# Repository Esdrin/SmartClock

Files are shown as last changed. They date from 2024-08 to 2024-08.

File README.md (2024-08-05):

# SmartClock

如你所见，这是一个基于`esp32的智能时钟`项目

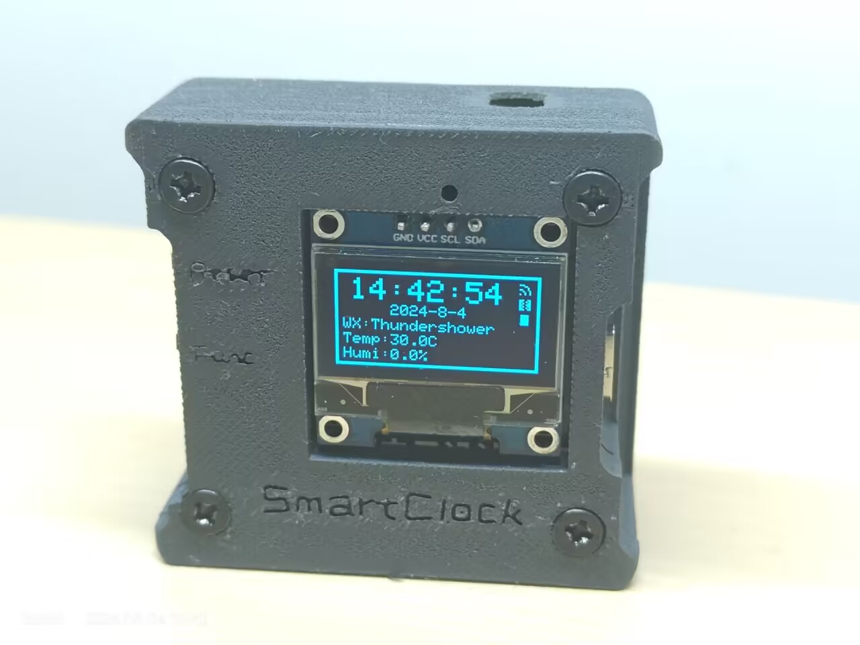
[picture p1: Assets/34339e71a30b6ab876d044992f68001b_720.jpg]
34339e71a30b6ab876d044992f68001b_720


## 前言

本项目自开始（`嘉立创第九届电子设计大赛`）至结束总共花了差不多`1个月`时间，我是一个电设小白，我在这一个月中学习了一些奇奇怪怪有用的知识，这边感谢一下群里的各位佬对我的大力支持，我能`独立完成`这个项目真的很开心（快猝死了）。

本项目为`首次公开`，为`本人原创`项目。项目`未曾在别的比赛中获奖`。

## 项目介绍

本项目是一款针对现代智能家居环境设计的`温湿度监测与时间管理装置`，旨在解决家庭及小型办公空间对环境舒适度与时间同步管理的需求。通过集成`ESP32微控制器`和`SHT40传感器`，我实现了一套`实时监测并远程报告室内温度和湿度`的系统，有效提升了居住和工作环境的舒适度。~~低功耗设计~~和`内置电池`确保了设备的持续运行，无需频繁充电。同时，模块`具备时钟`功能，解决了家中或办公室缺少统一时间显示的问题，方便用户安排日程。

## 复刻金额

如果你是一个专业的电子工程师，那么`复刻的成本在45RMB左右`。

如果不是，那么请准备好以下工具：焊台、电烙铁、热风枪等焊接器具。

## 功能列表

- [x] 温湿度检测（盛思锐的sht40模块）
- [x] 时间显示（网络ntp）
- [x] 日期显示（时间转换）
- [x] 天气显示（心知API）
- [x] 温度过热报警
- [x] MQTT服务的支持（或许你可以连到米家上？）
- [x] 允许使用web服务器进行配置
- [x] UI图像（自己画的，勿喷）

##  文件夹目录

- Firmware：本项目的代码，基于PlatformIO平台
- Model： 本项目的模型文件，基于soildworks 2024
- Picture：本项目的UI图片，自己PS画的
- OrderFile：下单文件
- Assets：Markdown资源文件

## 功能简介

### 主屏幕

如图所见，这是它的`主屏幕`。

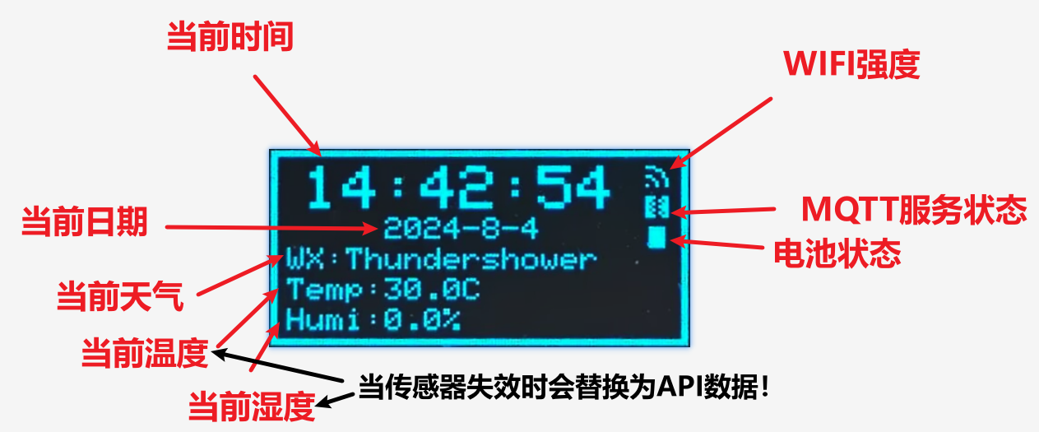
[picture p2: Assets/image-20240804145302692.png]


### 按钮功能

侧边使用双按钮，分别为`Reset（重置按钮）`和`Func（功能）`

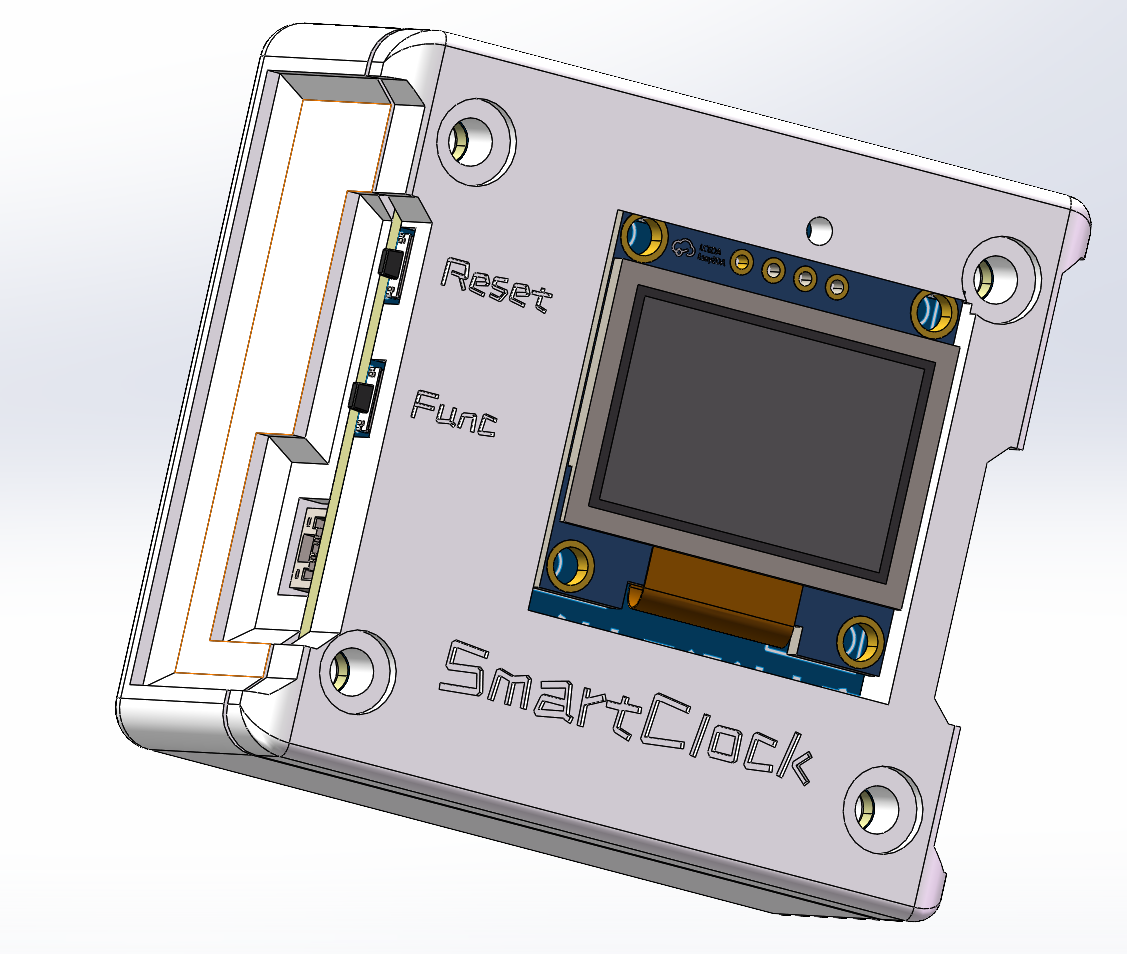
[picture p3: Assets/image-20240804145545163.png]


#### Reset按钮

- **重启**（按1s后松开）：`立马`校准时钟，天气等。
- **重置**（长按5s以上）：`重新设置`WIFI、服务器、天气API等参数。

#### Func按钮

等你创造（写一些时钟不该有的功能的任务就交给你们了！）

### 主控

采用esp32，集成WIFI、蓝牙，淘宝上15块钱包邮到家。

### 配置界面

第一次启动会自动进入配置模式，你也可以使用下面的`reset按键`进行重置参数后也会自动进入。

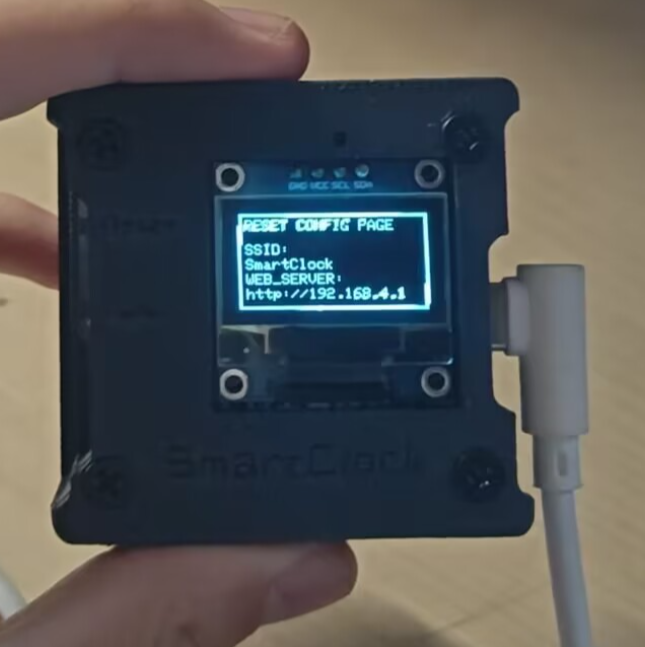
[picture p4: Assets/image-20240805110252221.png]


配置过程：

- 首先你需要找到一个叫做`SmartClock`的WIFI并`连接`。（可以在`Firmware/src/Config.h`中调节`AP_NAME`来更改WIFI名称）
- 浏览器中输入小屏幕中的`WEB_SERVER`地址，也可以下拉通知栏点击`登录到WLAN网络`。
- 按照下图进行配置具体参数。

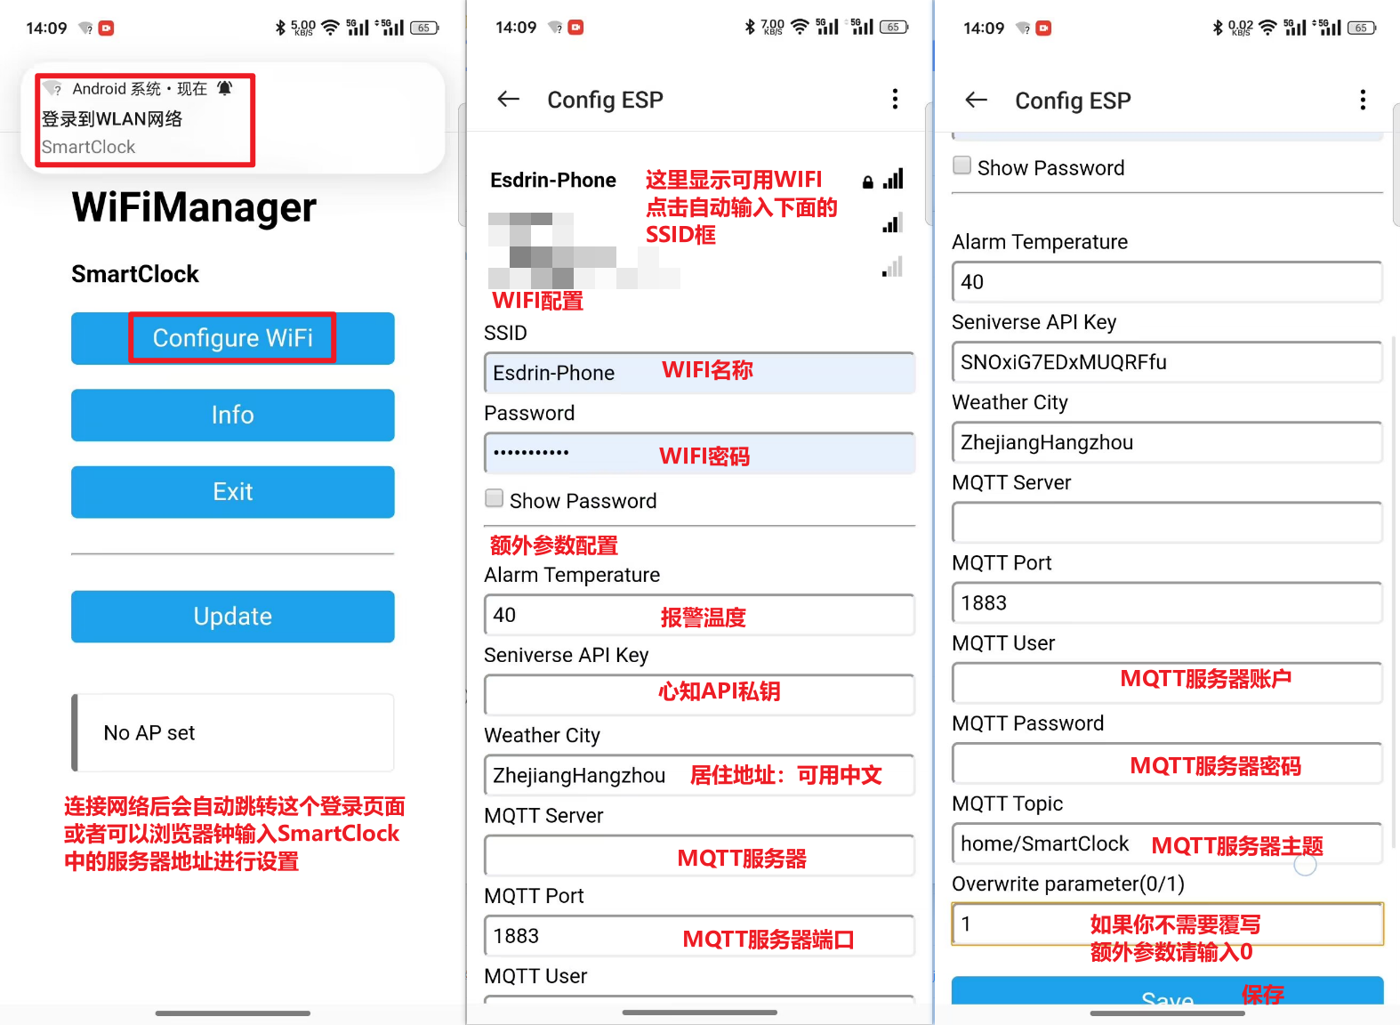
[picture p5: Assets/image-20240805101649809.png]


### 温度采集模块

采用`SHT40`模块，可以使用嘉立创的[SHT40-AD1B with pin模块](https://item.szlcsc.com/item/24072575.html),也可以淘宝上去买这个芯片（4块包邮）

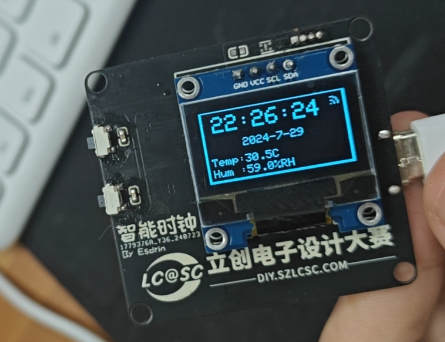
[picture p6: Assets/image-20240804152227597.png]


### OLED屏幕

采用`0.96寸OLED屏幕`，淘宝应该是13左右，立创商城价格和淘宝差不多。

### 天气

采用[心知天气API](https://www.seniverse.com/)，可以去他们官网申请他们的免费版本，在配置界面填入他们给的私钥以及您当前所属的区域就行。默认更新频率是`每2小时一次`，可以调节`Firmware/src/Config.h`中的`WEATHER_INTERVAL`进行配置

### MQTT

MQTT功能是为了一些大佬想把这个设备接入自己的生态的功能，他会以`每分钟1次`的频率向服务器发送温度传感器的数据，频率可以在`Firmware/src/Config.h`中调节`MQTT_PUBLISH_INTERVAL`进行控制。

### 温度报警

当`检测温度大于配置的值`的时候，将会给输出的口一个`高电平`，否则为低。（一般情况下用不到）

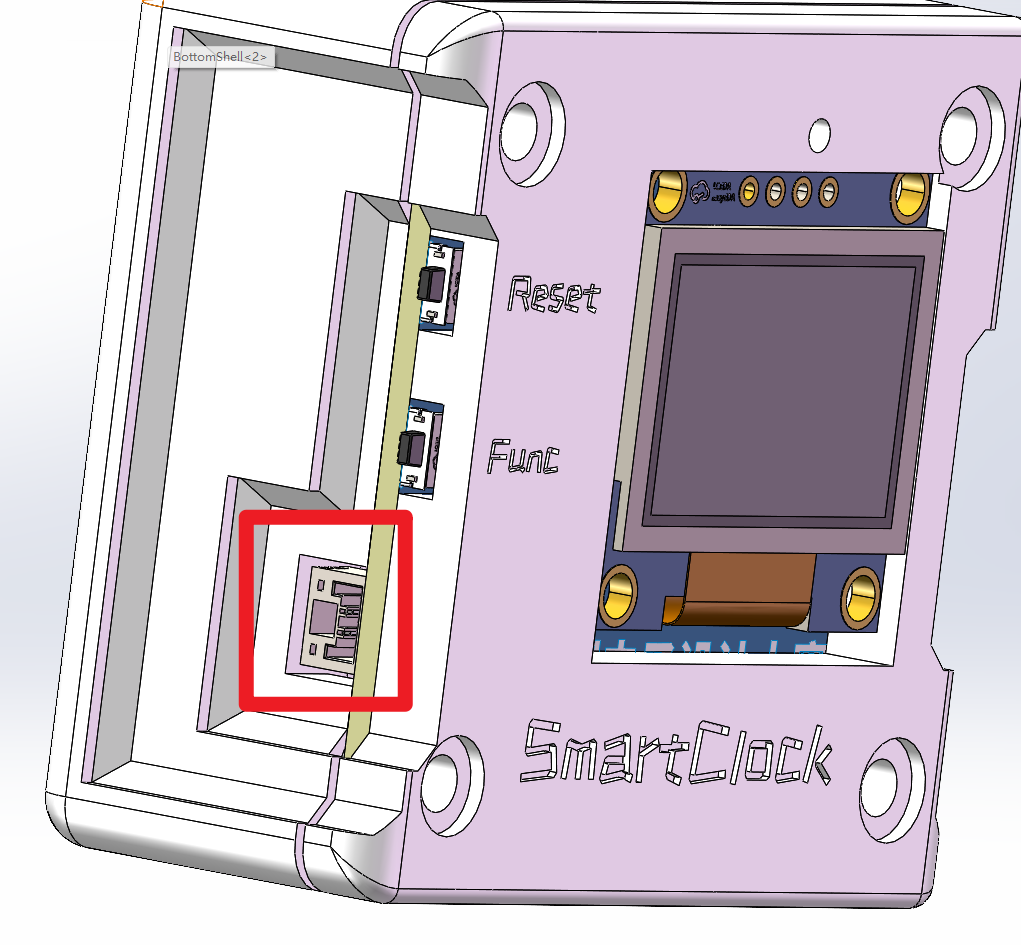
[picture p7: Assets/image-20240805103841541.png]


### 时钟

时钟主要以**本机时钟为主、网络时钟为辅**的策略，默认网络校准频率为`每10分钟一次`，可以调节`Firmware/src/Config.h`的`NTP_UPDATE_INTERVAL`进行配置。

**如果您不在中国**，想要改变时区，可以调节`Firmware/src/Config.h`的`TIME_OFFSET`参数。

**默认ntp（网络校准服务器）由阿里云提供**，可以在`Firmware/src/Config.h`的`NTP_SERVER`进行更改。

### 电池管理

电池采用：582728-400毫安（淘宝10块一个）

电池管理芯片：ME4064（5毛一个）

电源管理芯片：RT9013（好像也是5毛）

### PCB

这边就不得不夸一下**不以卖板赚钱，以培养工程师为己任**的`嘉立创集团`了，没错打板**免费**。（网上可以搜搜教程）

### 外壳及固定

外壳在附件中包含（Topshell以及BottomShell），外壳固定采用`M3*10的螺丝`，以及`M3的热熔螺母`

## 项目开源链接及协议

- [#第九届立创电赛#基于ESP32的多功能温度检测模块 - 嘉立创EDA开源硬件平台 (oshwhub.com)](https://oshwhub.com/esdrin/temperature-clock)
- [Esdrin/SmartClock (gitee.com)](https://gitee.com/esdrin/smart-clock)
- [Esdrin/SmartClock (github.com)](https://github.com/Esdrin/SmartClock)

**本项目采用GPL3.0开源协议**

## 鸣谢列表

### 提供器材以及设备

 - [嘉立创集团](https://www.jlcgroup.cn/)：提供本项目的PCB、元器件支持。
 - [盛思锐](https://sensirion.com/)：提供本项目的温湿度传感器模块。
 - [心知天气API](https://www.seniverse.com/):提供本项目天气功能的API接口。

### 感谢大佬们提供技术支持

 - 灵魂惊叹符<QQ：363109993>
 - 大肚腩小鼠鼠<QQ：1597167794>
 - 嘉立创陈工

**排名不分先后**

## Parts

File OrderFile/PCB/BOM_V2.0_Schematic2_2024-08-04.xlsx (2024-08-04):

No. | Quantity | Comment | Designator | Footprint | Value | Manufacturer Part | Manufacturer | Supplier Part | Supplier
1 | 9 | 100nF | C19,C21,C22,C24,C25,C26,C36,C37,C45 | C0603 | 100nF | CC0603KRX7R9BB104 | YAGEO(国巨) | C14663 | LCSC
2 | 1 | 22uF | C20 | C0603 | 22uF | CL10A226MQ8NRNC | SAMSUNG(三星) | C59461 | LCSC
3 | 6 | 10uF | C32,C33,C34,C35,C42,C44 | C0603 | 10uF | CL10A106KP8NNNC | SAMSUNG(三星) | C19702 | LCSC
4 | 1 | GH1.25-2PWBPZ | CN1 | CONN-SMD_GH1.25-2PWBPZ |  | GH1.25-2PWBPZ | BOOMELE(博穆精密) | C2829251 | LCSC
5 | 1 | GH1.25-2P | CN3 | CONN-SMD_2P-P1.25_GH1.25-2P |  | GH1.25-2P |  | C9900005837 | LCSC
6 | 1 | B340A | D2 | SMA_L4.3-W2.6-LS5.1-RD |  | B340A | MDD(辰达半导体) | C64982 | LCSC
7 | 2 | S8050 | Q1,Q2 | SOT-23-3_L2.9-W1.6-P1.90-LS2.8-BR |  | S8050 | Hottech(合科泰) | C181158 | LCSC
8 | 1 | AO3401 | Q3 | SOT-23-3_L2.9-W1.3-P1.90-LS2.4-BR |  | AO3401 | Hottech(合科泰) | C181091 | LCSC
9 | 1 | 1.5kΩ | R9 | R0603 | 1.5kΩ
10 | 3 | 10kΩ | R12,R13,R22 | R0603 | 10kΩ | 0603WAF1002T5E | UNI-ROYAL(厚声) | C25804 | LCSC
11 | 5 | 10kΩ | R14,R15,R16,R17,R20 | R0603 | 10kΩ | FRC0603J103TS | FOJAN(富捷) | C2930027 | LCSC
12 | 2 | 1kΩ | R18,R19 | R0603 | 1kΩ | RC0603FR-071KL | YAGEO(国巨) | C22548 | LCSC
13 | 1 | 3.3kΩ | R21 | R0603 | 3.3kΩ | 0603WAF3301T5E | UNI-ROYAL(厚声) | C22978 | LCSC
14 | 1 | 1kΩ | R23 | R0603 | 1kΩ | FRC0603J103TS | FOJAN(富捷) |  | LCSC
15 | 1 | 3.3kΩ | R24 | R0603 | 3.3kΩ | FRC0603J103TS | FOJAN(富捷) |  | LCSC
16 | 1 | 3.3kΩkΩ | R25 | R0603 | 3.3kΩkΩ | FRC0603J103TS | FOJAN(富捷) |  | LCSC
17 | 4 | M3螺丝 | SCREW1,SCREW2,SCREW3,SCREW4 | M3螺丝
18 | 2 | TS24CA | SW1,SW3 | SW-SMD_TS24CA |  | TS24CA | SHOU HAN(首韩) | C393942 | LCSC
19 | 1 | ESP32-WROOM-32E-N8 | U1 | WIFI-SMD_ESP32-WROOM-32E |  | ESP32-WROOM-32E-N8 | ESPRESSIF(乐鑫) | C701342 | LCSC
20 | 1 | SHT40-AD1B-R2 | U4 | DFN-4_L1.5-W1.5-P0.8-TL-EP |  | SHT40-AD1B-R2 | Sensirion(瑞士盛思锐) | C2909890 | LCSC
21 | 1 | CH340C | U8 | SOP-16_L10.0-W3.9-P1.27-LS6.0-BL |  | CH340C | WCH(南京沁恒) | C84681 | LCSC
22 | 1 | HS96L03W2C03 | U9 | OLED-TH_L27.8-W27.2-P2.54_C9900033791 |  | HS96L03W2C03 | HS(汉昇) | C5248080 | LCSC
23 | 1 | DW127R-11-04-34 | U10 | CONN-TH_4P-P1.27_DEALON_DW127R-11-04-34 |  | DW127R-11-04-34 | DEALON(德艺隆) | C2935874 | LCSC
24 | 1 | ME4064AM5G-N | U11 | SOT-23-5_L3.0-W1.7-P0.95-LS2.8-BR |  | ME4064AM5G-N | MICRONE(南京微盟) | C2765184 | LCSC
25 | 1 | RT9013-33GB | U13 | SOT-23-5_L2.9-W1.6-P0.95-LS2.8-BR |  | RT9013-33GB | TECH PUBLIC(台舟) | C19268157 | LCSC
26 | 1 | TYPE-C 16PIN 2MD(073) | USB1 | USB-C-SMD_TYPE-C-6PIN-2MD-073 |  | TYPE-C 16PIN 2MD(073) | SHOU HAN(首韩) | C2765186 | LCSC

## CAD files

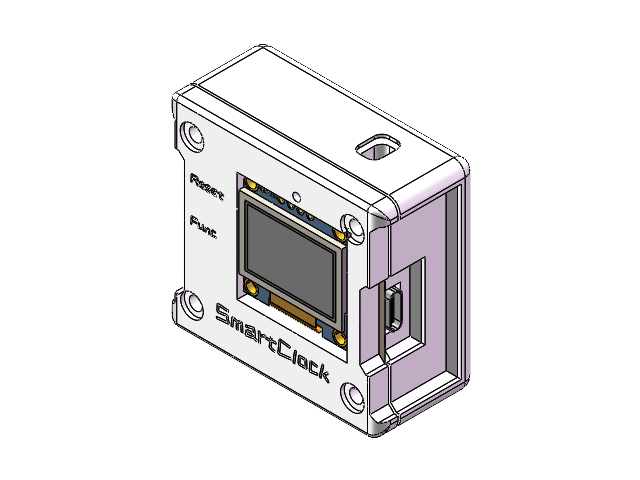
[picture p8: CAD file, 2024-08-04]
Model/ALL.SLDASM
零件1^5Jub-U9
TopSilk
BottomSilk
Board
BottomShell
TopShell

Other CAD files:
Model/PCB.SLDASM
Model/PCB_Node/5Jub-R23.SLDASM
Model/PCB_Node/SOP-16_L10.0-W3.9-P1.27-LS6.0-BL.SLDASM
Model/PCB_Node/5Jub-U4.SLDASM
Model/PCB_Node/SOT-23-3_L2.9-W1.6-P1.90-LS2.8-BR.SLDASM
Model/PCB_Node/5Jub-C35.SLDASM
Model/PCB_Node/5Jub-C19.SLDASM
Model/PCB_Node/CONN-SMD_GH1.25-2PWBPZ.SLDASM
Model/PCB_Node/5Jub-U13.SLDASM
Model/PCB_Node/5Jub-Q1.SLDASM
Model/PCB_Node/5Jub-C24.SLDASM
Model/PCB_Node/5Jub-C26.SLDASM
Model/PCB_Node/5Jub-CN3.SLDASM
Model/PCB_Node/5Jub-R14.SLDASM
Model/PCB_Node/5Jub-C34.SLDASM
Model/PCB_Node/5Jub-R13.SLDASM
Model/PCB_Node/5Jub-U10.SLDASM
Model/BottomShell.SLDPRT
Model/PCB_Node/5Jub-C20.SLDASM
Model/PCB_Node/5Jub-C21.SLDASM
Model/PCB_Node/5Jub-C22.SLDASM
Model/PCB_Node/5Jub-C25.SLDASM
Model/PCB_Node/5Jub-C32.SLDASM
Model/PCB_Node/5Jub-C33.SLDASM
Model/PCB_Node/5Jub-C36.SLDASM
Model/PCB_Node/5Jub-C37.SLDASM
Model/PCB_Node/5Jub-C42.SLDASM
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

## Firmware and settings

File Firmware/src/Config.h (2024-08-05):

// 板名称
#define AP_NAME "SmartClock"

// NTP服务器设置
#define NTP_SERVER "ntp1.aliyun.com"
#define NTP_UPDATE_INTERVAL 10*60*1000
// 时区设置
#define TIME_OFFSET 28800

// 板配置
#define RESET_PIN 19
#define FUNC_PIN 18
#define PLUG_PIN 32
#define BAT_ADC_PIN 33
#define TEMP_OUTPUT_PIN 13

// ADC 配置
#define ADC_RESOLUTION 4095.0
#define ADC_VREF 3.3
#define ADC_OFFSET 0.0


// i2c 设置
#define SDA_pin 21
#define SCL_pin 22

// 电池配置
#define BAT_FULL_VOL 4.2
#define BAT_EMPTY_VOL 3.5
#define BAT_UP_REG 1500.00
#define BAT_DOWN_REG 3300.00

// OLED显示屏设置
#define SCREEN_ADDRESS  0x3C
#define SCREEN_WIDTH    128
#define SCREEN_HEIGHT   64
#define SCREEN_RESET    -1


// MQTT 配置
#define MQTT_PUBLISH_INTERVAL 60*1000

// WIFI配置
#define WIFI_RECONNECT_INTERVAL 30*1000

// 天气API配置
#define WEATHER_INTERVAL 2*60*60*1000
